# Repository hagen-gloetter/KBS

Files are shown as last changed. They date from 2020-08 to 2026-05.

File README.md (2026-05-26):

# KBS – Kinder Benachrichtigungs System

**English:** Tired of shouting through the house to call the kids for dinner or to get up? The Child Notification System (KBS) is a Raspberry Pi-based solution using a 16x2 LCD display and a piezo buzzer. Messages are sent via a REST API, so any system capable of HTTP POST requests can trigger notifications.

**Deutsch:** Ist es nicht nervig, immer durch das Haus oder die Wohnung zu brüllen, um die Kinder zum Essen oder Aufstehen zu rufen? Das Kinder Benachrichtigungs System (KBS) löst genau dieses Problem. Das System basiert auf einem Raspberry Pi (Zero), einem 16x2 LCD-Display und einem Piezo-Buzzer. Das Display und der Buzzer werden über eine REST-API angesteuert.

## Architektur

```
┌──────────────┐     HTTP POST      ┌──────────────────┐
│  Webserver   │ ─────────────────> │  Raspberry Pi    │
│  (PHP)       │                    │  Flask API :8080 │
│              │                    │  LCD + Buzzer    │
└──────────────┘                    └──────────────────┘
```

- **Webserver** (`webserver/`): PHP-basierte Weboberfläche zum Senden von Nachrichten (Vanilla JS, keine externen Abhängigkeiten)
- **Display-Server** (`display/`): Flask REST-API auf dem Raspberry Pi, steuert LCD und Buzzer
- **3D-Gehäuse** (`3d-case/`): 3D-Druck-Dateien für das Gehäuse
- **Schaltplan** (`wiring-diagram/`): Fritzing-Datei für die Verkabelung

## Hardware

- Raspberry Pi Zero (oder vergleichbar)
- 16x2 LCD-Display mit I2C-Adapter (Adresse: `0x27`)
- Piezo-Buzzer (an GPIO Pin 15)
- Verkabelung:
  - Display: GPIO2/SDA (Pin 3), GPIO3/SCL (Pin 5)
  - Buzzer: GPIO 15 + Ground

## Installation

### Raspberry Pi vorbereiten

```bash
# Repository klonen
git clone <repository-url> ~/kbs
cd ~/kbs

# Setup-Skript ausführen (installiert Abhängigkeiten, aktiviert I2C)
sudo bash setup.sh
```

### Cronjob einrichten

```bash
# Crontab bearbeiten
crontab -e

# Folgende Zeilen einfügen:
@reboot /bin/bash /home/pi/kbs/crontab.sh
*/1 * * * * /usr/bin/python3 /home/pi/kbs/display/lcd_off.py
```

Der Cronjob startet den Flask-Server beim Boot und schaltet das Display nach 5 Minuten Inaktivität ab.

### Webserver einrichten

Die Dateien aus `webserver/` auf einen Webserver mit PHP und cURL-Unterstützung kopieren:

```bash
# Beispiel: Deployment auf den Webserver
rsync -ave ssh webserver/* user@webserver:/var/www/html/
```

## Verwendung

### REST-API (direkt)

```bash
curl -i -H "Content-Type: application/json" \
  -X POST \
  -d '{"line1":"Essen ist", "line2":"fertig!", "bell":"on", "display":"on"}' \
  http://<pi-ip>:8080/lcd/api/v1.0/lcds
```

Parameter:
| Parameter | Beschreibung | Werte |
|---|---|---|
| `line1` | Erste Zeile (max. 16 Zeichen) | Text |
| `line2` | Zweite Zeile (max. 16 Zeichen) | Text |
| `bell` | Buzzer abspielen | `on` / `off` |
| `display` | Display blinken lassen | `on` / `off` |

### Post-API (für externe Systeme)

Die `post.php` bietet eine einfache HTTP-Schnittstelle für Homeautomation-Systeme oder Skripte:

```bash
curl -X POST http://<webserver>/post.php \
  -d "line1=Essen ist" \
  -d "line2=fertig!" \
  -d "bell=on" \
  -d "display=on" \
  -d "person=K0"
```

Parameter:
| Parameter | Beschreibung | Werte | Default |
|---|---|---|---|
| `line1` | Erste Zeile (max. 16 Zeichen) | Text | Datum |
| `line2` | Zweite Zeile (max. 16 Zeichen) | Text | Uhrzeit |
| `bell` | Buzzer abspielen | `on` / `off` | `off` |
| `display` | Display blinken lassen | `on` / `off` | `off` |
| `person` | Zielperson | `K0` (alle) / `K1` / `K2` / `K3` | `K0` |

Antwort: JSON mit Ergebnis pro Ziel-Pi.

### Weboberfläche

Die PHP-Weboberfläche bietet:
- Vordefinierte Nachrichtenvorlagen (`texte.json`)
- Auswahl der Zielperson (einzelne Kinder oder alle)
- Klingel- und Blink-Optionen

## Deployment

```bash
# Auf alle Raspberry Pis und den Webserver deployen
bash deploy.sh
```

## Projektstruktur

```
KBS/
├── display/                # Flask-Server und Hardware-Steuerung
│   ├── socket_server.py    # Haupt-Server (aktuelle Version)
│   ├── bootscreen.py       # Zeigt Hostname/IP beim Boot
│   ├── buzzer3.py          # Buzzer-Steuerung
│   ├── lcd_blink.py        # Display-Blink-Funktion
│   ├── lcd_off.py          # Display-Abschaltung (Cronjob)
│   ├── lcddriver.py        # LCD I2C-Treiber
│   └── i2c_lib.py          # I2C-Bibliothek
├── webserver/              # PHP-Weboberfläche
│   ├── config.php          # Zentrale Konfiguration (Hosts, Ports, Personen)
│   ├── index.php           # Haupt-UI
│   ├── post.php            # API-Proxy (mit Zielauswahl)
│   ├── edit.php            # Vorlagen-Editor (Legacy)
│   ├── texte.json          # Nachrichtenvorlagen
│   └── css/style.css       # Eigenes CSS (keine externen Abhängigkeiten)
├── 3d-case/                # 3D-Druck-Dateien
├── wiring-diagram/         # Fritzing-Schaltplan
├── setup.sh                # Installations-Skript
├── deploy.sh               # Deployment-Skript
├── crontab.sh              # Startup-Skript
└── crontab-install.txt     # Crontab-Vorlage
```

## Konfiguration

Alle netzwerkspezifischen Einstellungen werden zentral in `webserver/config.php` verwaltet:

```php
$KBS_TARGETS = array(
    'K1' => array('name' => 'Ramona', 'host' => 'pi-zero1.fritz.box', 'emoji' => '&#x1F467;'),
    'K2' => array('name' => 'Denise', 'host' => 'pi-zero2.fritz.box', 'emoji' => '&#x1F467;'),
    'K3' => array('name' => 'Vater',  'host' => 'pi-zero3.fritz.box', 'emoji' => '&#x1F468;'),
);
```

Neue Personen/Pis können einfach als weitere Einträge ergänzt werden. Die Weboberfläche generiert die Radio-Buttons automatisch aus dieser Konfiguration.

Weitere Einstellungen:
- `KBS_API_PORT` — Port der Flask-Server (Default: 8080)
- `KBS_CURL_TIMEOUT` — cURL-Timeout in Sekunden (Default: 10)
- `KBS_CURL_CONNECT_TIMEOUT` — Connect-Timeout (Default: 5)

Die Deployment-Ziele in `deploy.sh` müssen separat angepasst werden.

## Bekannte Einschränkungen

- Keine Authentifizierung auf der REST-API (nur für lokale Netzwerke geeignet)
- Maximale Textlänge: 16 Zeichen pro Zeile (Hardware-Limitation)
- `socket_server_v1.py`, `socket_server_v2.py`, `socket_server_v3.py` sind ältere Entwicklungsversionen
- `buzzer.py`, `buzzer2.py` sind ältere Test-Dateien (Python 2-Syntax, nicht aktiv genutzt)
- `template.html`, `edit.php`, `styles.css` sind Legacy-Dateien (nicht aktiv genutzt)

## Lizenz

Siehe Projektdateien.

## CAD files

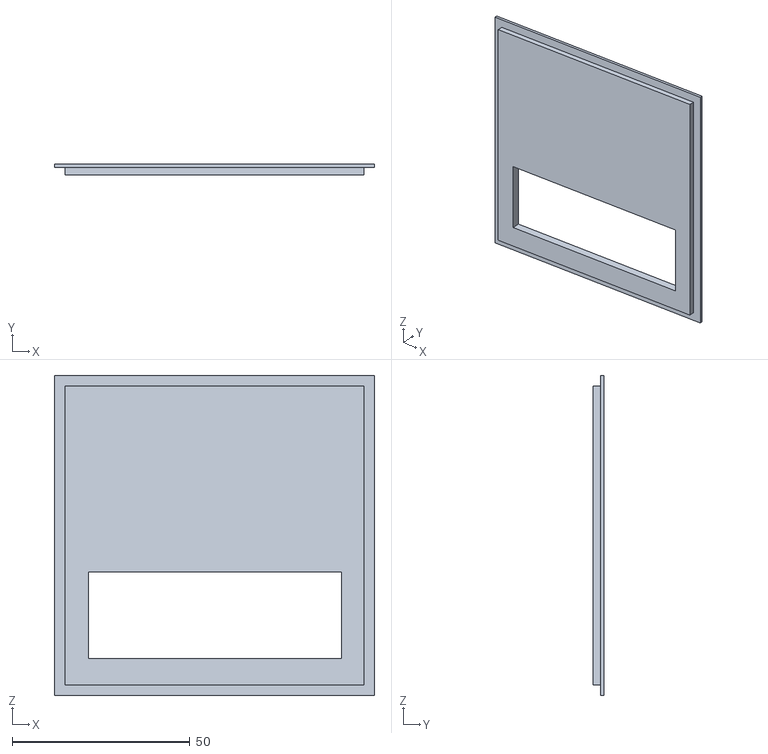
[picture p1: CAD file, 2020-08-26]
3d-case/Display Deckel v7.stl
90.0 x 3.00 x 90.0

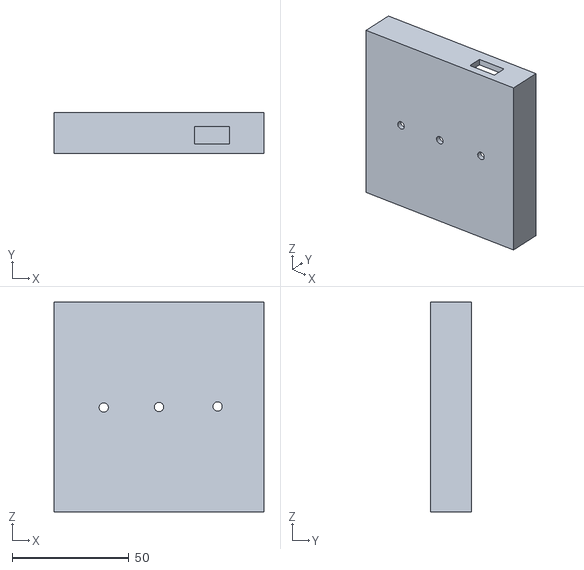
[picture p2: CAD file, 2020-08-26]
3d-case/Display Body v7.stl
90.0 x 17.5 x 90.0

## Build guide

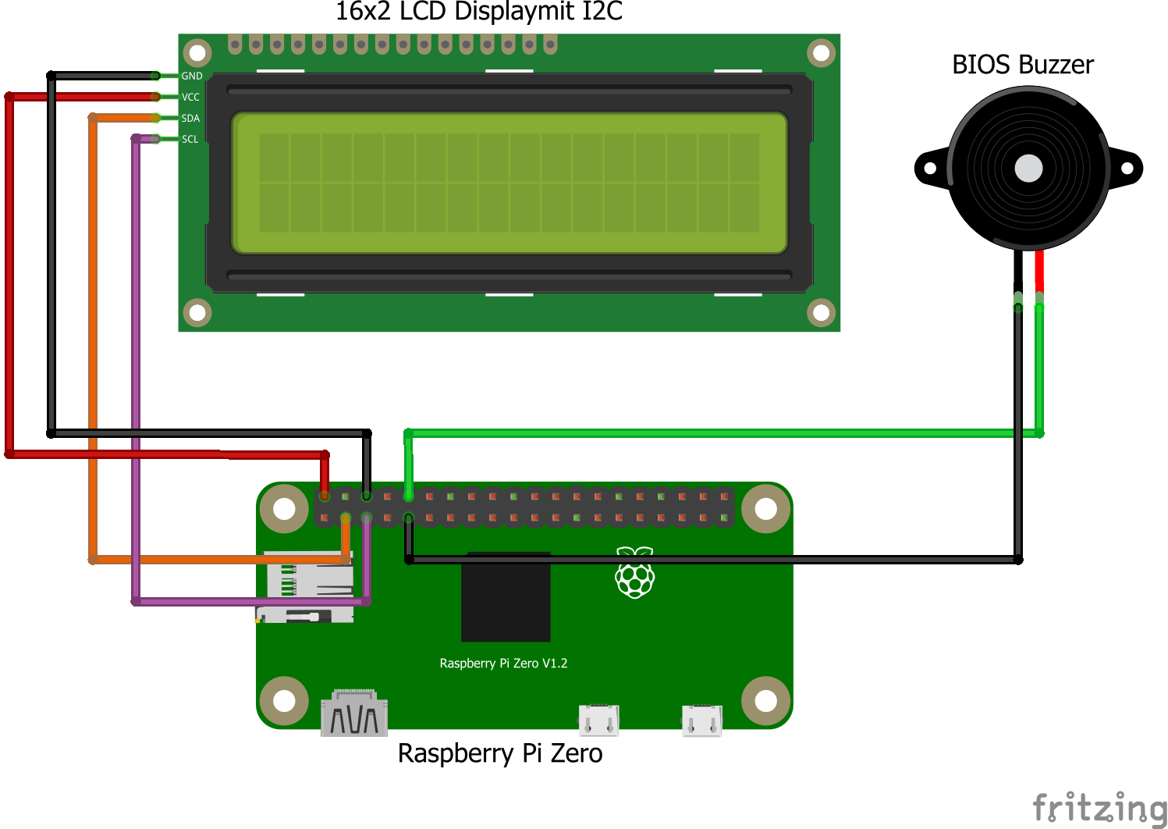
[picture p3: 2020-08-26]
wiring-diagram/KBS-KinderBenachrichtigungsSystem_Steckplatine.png

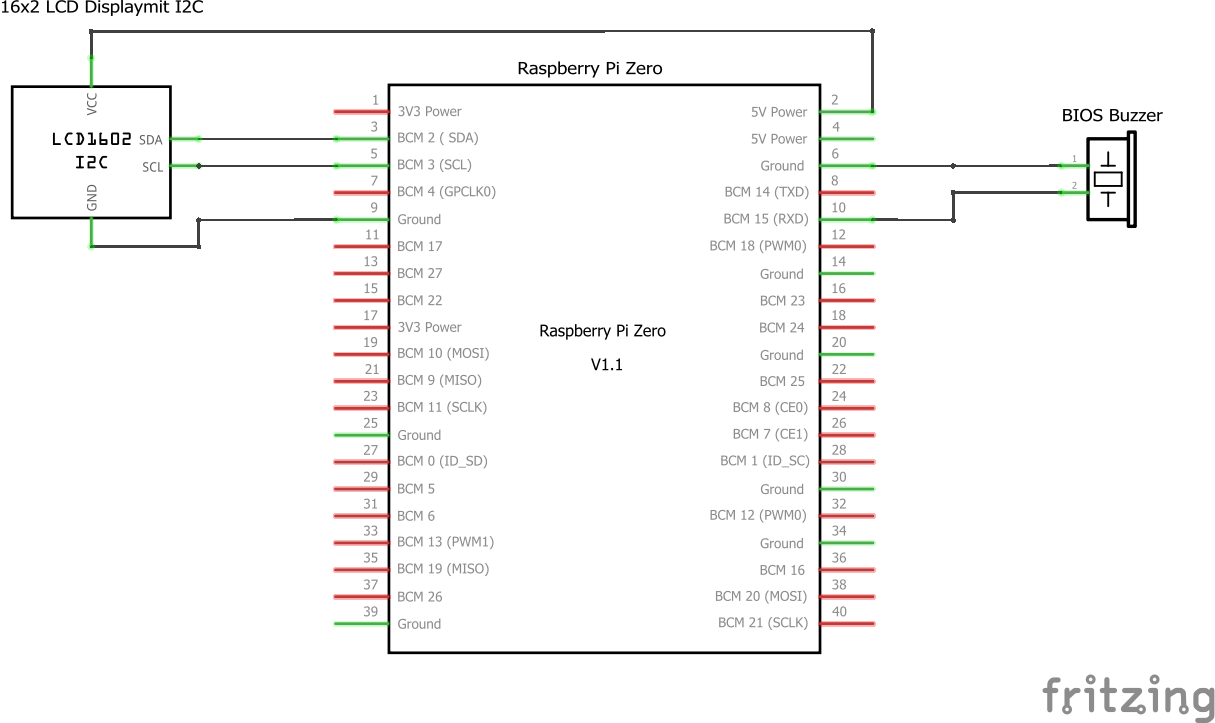
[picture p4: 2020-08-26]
wiring-diagram/KBS-KinderBenachrichtigungsSystem_Schaltplan.png

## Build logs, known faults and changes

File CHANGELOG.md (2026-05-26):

# Changelog

Alle wesentlichen Änderungen an diesem Projekt werden in dieser Datei dokumentiert.

Das Format basiert auf [Keep a Changelog](https://keepachangelog.com/de/1.0.0/),
und dieses Projekt verwendet [Semantic Versioning](https://semver.org/lang/de/).

## [Unreleased]

### Removed
- **[Medium]** jQuery 3.7.1 komplett entfernt — kein JavaScript-Framework mehr nötig
- **[Medium]** Bootstrap 4 CSS und JS komplett entfernt — kein CSS-Framework mehr nötig
- **[Medium]** Unbenutzte JS-Dateien gelöscht: `jquery-3.7.1.min.js`, `jquery.min.js`, `popper.min.js`, `bootstrap.min.js`, `scripts.js`
- **[Medium]** Unbenutzte CSS-Dateien gelöscht: alle `bootstrap*.css` und zugehörige `.map`-Dateien
- **[Low]** Leeres `webserver/fonts/`-Verzeichnis gelöscht
- **[Low]** IE-Edge-Compatibility Meta-Tag (`X-UA-Compatible`) entfernt (veraltet, nicht mehr relevant)
- **[Low]** Bootstrap-spezifische `data-dismiss`-Attribute durch Vanilla JS `onclick`-Handler ersetzt

### Added
- **[Medium]** `config.php`: Zentrale Konfigurationsdatei für Pi-Hostnamen, Ports, Timeouts und Personenzuordnungen
- **[Medium]** `post.php`: Optionaler `person`-Parameter für Zielauswahl (K0=alle, K1/K2/K3=einzeln)
- **[Medium]** `post.php`: Multi-Target-Unterstützung — sendet an mehrere Pis und gibt Ergebnis pro Ziel zurück
- **[Medium]** Vollständig eigenes CSS (`css/style.css`) mit CSS Custom Properties, modernen Toggle-Switches, Custom Radio-Buttons, Card-Layout, Responsive Design
- **[Medium]** Vanilla JavaScript für Vorlagen-Laden (`fetch()` API statt jQuery `$.getJSON()`)
- **[Medium]** CSS-only Toggle-Switches statt Bootstrap Custom Switches
- **[Medium]** CSS-only Custom Radio-Buttons mit Übergangsanimationen
- **[Low]** Docstrings und Modul-Header für alle Python-Dateien hinzugefügt
- **[Low]** PHPDoc-Blöcke für PHP-Dateien hinzugefügt
- **[Low]** Kommentare für Shell-Skripte (`setup.sh`, `deploy.sh`, `crontab.sh`) ergänzt
- **[Low]** CSS-Animation `alertSlideIn` für Statusmeldungen
- **[Low]** Responsive Media-Queries für Mobile-Geräte (< 480px)
- **[Low]** CSS-Placeholder-Styling für LCD-Eingabefelder

### Changed
- **[Medium]** `index.php`: Pi-Targets über `config.php` statt hardcoded Arrays
- **[Medium]** `index.php`: Radio-Buttons werden dynamisch aus `$KBS_TARGETS` generiert
- **[Medium]** `index.php`: cURL-Timeouts über Konstanten aus `config.php`
- **[Medium]** `index.php`: Komplettes Frontend-Rewrite ohne externe Abhängigkeiten (jQuery, Bootstrap)
- **[Medium]** `index.php`: Alert-HTML vereinfacht (`alert-close` + `onclick` statt Bootstrap JS)
- **[Medium]** `post.php`: Nutzt jetzt `config.php` für Ziel-URLs statt hardcoded `pi-zero1`
- **[Low]** `buzzer2.py`: Niederländische Kommentare und Texte ins Englische übersetzt
- **[Low]** Version-Bump von v2.0 auf v3.0
- **[Low]** `README.md`: Konfiguration, post.php-API und Legacy-Dateien dokumentiert

### Fixed (Legacy-Dateien)
- **[High]** `buzzer.py`: Tune 2 Duration-Bug — `[0.2,0.2,0.2,0.2,0.2,0,5]` → `[0.2,0.2,0.2,0.2,0.5]`
- **[High]** `buzzer.py`: GPIO-Pin-Kommentar korrigiert (sagte Pin 5, war bereits Pin 15)
- **[High]** `buzzer.py`: `__main__`-Guard mit Input-Validierung und `GPIO.cleanup()` im `finally`-Block
- **[High]** `buzzer2.py`: Python 2 Print-Syntax `print "text"` → Python 3 `print("text")`
- **[High]** `buzzer2.py`: GPIO-Pin von 5 auf 15 korrigiert (konsistent mit Hardware-Doku)
- **[High]** `socket_server_v1.py`: Fehlende Imports `abort`, `make_response` ergänzt
- **[High]** `socket_server_v1.py`: Task-Dictionary speicherte String-Literale `"line1"` statt Variablen
- **[High]** `socket_server_v1.py`: Python 2 Print-Syntax in `lcd_off_timer()` → Python 3
- **[High]** `socket_server_v1.py`: Port von 80 auf 8080 korrigiert (konsistent mit aktuellem Server)
- **[High]** `socket_server_v2.py`: Fehlende Imports `abort`, `make_response` ergänzt
- **[High]** `socket_server_v2.py`: `play()`-Methode war außerhalb der Buzzer-Klasse (falsche Einrückung)
- **[High]** `socket_server_v2.py`: Task-Dictionary speicherte String-Literale statt Variablen
- **[High]** `socket_server_v2.py`: `pass` statt `return jsonify()` in `create_task()` behoben
- **[High]** `socket_server_v2.py`: Tune 2 Duration-Bug behoben
- **[High]** `socket_server_v2.py`: GPIO-Pin von 5 auf 15 korrigiert
- **[Medium]** `socket_server_v2.py`: Nicht-funktionales `asyncio`-Import und Decorators entfernt
- **[High]** `socket_server_v3.py`: Gleiche Fixes wie v2 (Imports, play()-Einrückung, Task-Dict, return, Tune 2, Pin)
- **[Medium]** `socket_server_v3.py`: Nicht verfügbares `grequests`-Import entfernt
- **[Medium]** `template.html`: Referenzen auf gelöschte Bootstrap/jQuery-Dateien entfernt
- **[Medium]** `template.html`: Doppelte Radio-Button-ID `optionsRadios2` → `optionsRadios2a`
- **[Medium]** `template.html`: Base64-Data-URI-Inline-Styles aus Input-Feldern entfernt
- **[Low]** `template.html`: LayoutIt-Meta-Tags entfernt, IE-Compat-Meta entfernt
- **[Medium]** `edit.php`: Externes Google Fonts CDN entfernt (Datenschutz/Privacy)
- **[Low]** `edit.php`: Tutorial-Variablennamen (`superHeroes`, `heroes`) durch `jsonData`, `templates` ersetzt
- **[Low]** `edit.php`: `populateHeader()` auf KBS-Felder angepasst statt Tutorial-Felder

### Security
- **[Critical]** jQuery 3.3.1 → 3.7.1 aktualisiert (CVE-2020-11022, CVE-2020-11023, CVE-2019-11358)
- **[High]** jQuery wird jetzt lokal geladen statt vom CDN (keine externe Abhängigkeit, kein Supply-Chain-Risiko)
- **[Critical]** XSS-Schwachstelle in `index.php` durch unsanitisiertes `$_SERVER['PHP_SELF']` behoben
- **[Critical]** OS-Command-Injection in `socket_server.py` behoben — `os.system()` durch `subprocess.Popen()` ersetzt
- **[Critical]** Uninitialisiertes `$myObj` in `index.php` und `post.php` behoben
- **[High]** Fehlende `htmlspecialchars()`-Sanitisierung für `$person` in `index.php` hinzugefügt
- **[High]** Fehlende Input-Validierung in Flask-API — JSON-Felder werden jetzt sicher mit `.get()` und Defaults gelesen
- **[High]** Input-Sanitisierung für LCD-Text hinzugefügt (Längenbegrenzung, Steuerzeichen-Filter)
- **[High]** XSS in `index.php` `send_message_to_pi()` — URL/Content werden jetzt escaped in Fehlermeldungen
- **[Medium]** XSS in `index.php` value-Attributen — `$line1`/`$line2` Output jetzt mit `htmlspecialchars()`
- **[Medium]** jQuery CDN-Einbindung mit SRI-Hash (Subresource Integrity) abgesichert
- **[Medium]** cURL-Timeout (10s) und Connect-Timeout (5s) in `send_message_to_pi()` hinzugefügt

### Fixed
- **[High]** Fehlende Imports (`abort`, `make_response`) in `socket_server.py` ergänzt
- **[High]** Unbenutzte Imports (`requests`, `threading`, `Response`, `RPi.GPIO`) in `socket_server.py` entfernt
- **[High]** Switch-Statement-Bug in `index.php`: `case 200 || 201:` (immer `true`) zu separaten Cases korrigiert
- **[High]** `curl_errno()` nach `curl_close()` in `index.php` behoben — Fehler wird jetzt vor dem Schließen gespeichert
- **[High]** Tautologische Bedingung bei Radio-Buttons in `index.php` korrigiert (`||` → `&&`)
- **[High]** `post.php`: Variable `$display` wurde mit `$_POST['zielperson']` überschrieben
- **[High]** `post.php`: Ungültiges `return` auf Top-Level entfernt
- **[High]** Task-Dictionary in `socket_server.py` speicherte String-Literale statt Variablenwerte
- **[High]** `bootscreen.py`: `not in` → `!=` — Substring-Check statt Gleichheitsprüfung ergab falsche Ergebnisse
- **[High]** `lcddriver.py`: Backlight-State-Tracking — Backlight wurde bei jedem `lcd_write()` wieder eingeschaltet, da `LCD_BACKLIGHT` hardcoded war. Jetzt wird `self.backlight_state` in `lcd_strobe()` und `lcd_write_four_bits()` verwendet
- **[High]** `buzzer3.py`: Tune 2 Duration-Bug — `[0.2,0.2,0.2,0.2,0.2,0,5]` war `0` und `5` statt `0.5`, Array hatte 7 Elemente für 5 Pitches
- **[Medium]** `bootscreen.py`: Python 3-Kompatibilität für `struct.pack()` (bytes statt string)
- **[Medium]** `lcd_blink.py`: Validierungslogik `or` → `and` (war immer true)
- **[Medium]** `lcd_off.py`: Fehlender `if __name__ == '__main__'`-Guard hinzugefügt
- **[Medium]** `lcd_off.py`: Doppelter `__main__`-Block entfernt
- **[Medium]** `lcd_off.py`: Unnötiger `heute.weekday()`-Aufruf ohne Zuweisung entfernt
- **[Medium]** `lcd_off.py`: Wochentagsnamen auf 2 Zeichen gekürzt (Zeile 2 passte nicht in 16 Zeichen, z.B. "Donnerstag, 13.05." = 20 Zeichen)
- **[Medium]** `lcddriver.py`: `sys.path.append("./lib")` durch absoluten Pfad ersetzt — funktioniert jetzt auch wenn aus anderem Verzeichnis gestartet (z.B. Crontab)
- **[Medium]** `i2c_lib.py`: Wildcard-Import `from time import *` durch `from time import sleep` ersetzt
- **[Medium]** `lcddriver.py`: Wildcard-Import `from time import *` durch `from time import sleep` ersetzt
- **[Medium]** `i2c_lib.py`: Unnötiges `sys.path.append("./lib")` entfernt
- **[Medium]** `socket_server.py`: File-Handle-Leak bei lastrun-Erstellung behoben (`with`-Statement)
- **[Medium]** `index.php`: Variable `$person` im else-Branch initialisiert (vermeidet undefined-Warnung)
- **[Medium]** `index.php`: Zero-Width-Character (U+200B) im HTML entfernt
- **[Medium]** `crontab-install.txt`: Falscher Pfad `16x2_Display` → `kbs` korrigiert
- **[Medium]** `crontab.sh`: `python` → `python3` für bootscreen.py; stderr-Redirect hinzugefügt
- **[Low]** `socket_server.py`: Tasks-Liste auf 100 Einträge begrenzt (Memory-Leak verhindert)

### Changed
- **[Medium]** `setup.sh`: Python 2-Abhängigkeiten entfernt, nur noch Python 3
- **[Medium]** `setup.sh`: `/etc/modules`-Einträge werden nur hinzugefügt wenn nicht vorhanden
- **[Medium]** `setup.sh`: `-y` Flag für `apt-get install` hinzugefügt
- **[Medium]** `setup.sh`: Nutzt jetzt `requirements.txt` statt manueller `pip3 install`-Befehle
- **[Low]** `deploy.sh`: Excludes für `.git`, `__pycache__`, Logs, `3d-case`, `wiring-diagram`, `webserver/`, Docs
- **[Low]** `lcd_off.py`: Unbenutzten `RPi.GPIO`-Import und doppelte `strftime`-Aufrufe entfernt
- **[Low]** `lcddriver.py`: `lcd_backlight()` nutzt `state.lower()` statt expliziter Aufzählung
- **[Medium]** `post.php`: Komplett modernisiert — Port 8080, Timeout, JSON-Response, sauberes Error-Handling

### Added
- `requirements.txt` für Python-Abhängigkeiten erstellt
- `.gitignore` erstellt
- `CHANGELOG.md` erstellt
- `SECURITY.md` erstellt
- `README.md` umfassend aktualisiert mit Setup-Anleitung, API-Dokumentation und Projektstruktur
- `socket_server.py`: Error-Handler für 400 Bad Request hinzugefügt
- `socket_server.py`: Health-Endpoint (`GET /health`) und GET-Endpoint für alle Tasks
- `socket_server.py`: Task-IDs und Timestamps für jeden gesendeten Task
- `socket_server.py`: Strukturiertes Logging mit Zeitstempel statt print()
- `socket_server.py`: JSON-Info auf Root-Endpoint (`/`) mit API-Übersicht
- `index.php`: Komplettes Webseiten-Redesign mit modernem Card-Layout
- `index.php`: LCD-Vorschau-Styling (monospace, grüne Schrift auf dunkelgrün)
- `index.php`: Vorlagen werden bei Select-Änderung automatisch übernommen
- `index.php`: Pi-Targets als konfigurierbare Array-Struktur statt if/elseif-Kette
- `index.php`: Status-Alerts pro Pi (einzelne Erfolg/Fehler-Meldungen)
- `css/style.css`: Eigenes CSS mit Cards, Shadows, abgerundeten Ecken
- `js/jquery-3.7.1.min.js`: jQuery lokal eingebunden

### Improved
- `bootscreen.py`: Socket wird jetzt geschlossen, LCD in main() initialisiert, saubere Fehlerbehandlung
- `bootscreen.py`: get_ip() gibt Exception-basiert "Not connected" zurück statt finally-return
- `bootscreen.py`: Hostname wird nur einmal ermittelt statt in jeder Schleife
- `lcd_blink.py`: Unbenutzter RPi.GPIO-Import entfernt, Eingabe-Validierung mit ValueError-Handling
- `buzzer3.py`: GPIO.cleanup() im finally-Block, Input-Validierung mit Bereichsprüfung
- `texte.json`: Vorlagen auf max. 16 Zeichen korrigiert, konsistente Formatierung
- `texte.json`: "Aufstehen" und "SOFORT"-Vorlagen mit Blinken aktiviert

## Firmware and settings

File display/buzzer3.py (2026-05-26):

#! /usr/bin/python3
# -*- coding: utf-8 -*-
#
# KBS – Buzzer-Steuerung (aktive Version)
# Spielt verschiedene Melodien ueber einen Piezo-Buzzer an GPIO Pin 15.
#
# Verwendung: python3 buzzer3.py <Tune 1-5>
#
# Tunes:
#   1 – Tonleiter auf/ab (C4-C6)
#   2 – Aufsteigend kurz
#   3 – Melodie mit Pausen
#   4 – Absteigend hoch
#   5 – Absteigend tief
#
# Hardware: Piezo-Buzzer an GPIO 15 + Ground
#

import RPi.GPIO as GPIO   #import the GPIO library
import time               #import the time library
import sys


class Buzzer(object):
 def __init__(self):
  GPIO.setmode(GPIO.BCM)  
  self.buzzer_pin = 15 #set to GPIO pin 15
  GPIO.setup(self.buzzer_pin, GPIO.IN)
  GPIO.setup(self.buzzer_pin, GPIO.OUT)
  print("buzzer ready")

 def __del__(self):
  class_name = self.__class__.__name__
  print (class_name, "finished")
  
 def buzz(self,pitch,duration):
  if(pitch==0):
   time.sleep(duration)
   return
  period = 1.0 / pitch     #in physics, the period (sec/cyc) is the inverse of the frequency (cyc/sec)
  delay = period / 2     #calcuate the time for half of the wave  
  cycles = int(duration * pitch)   #the number of waves to produce is the duration times the frequency

  for i in range(cycles):
   GPIO.output(self.buzzer_pin, True)   #set pin 18 to high
   time.sleep(delay)
       #wait with pin 18 high
   GPIO.output(self.buzzer_pin, False)
       #set pin 18 to low
   time.sleep(delay)
       #wait with pin 18 low

 def play(self, tune):
  GPIO.setmode(GPIO.BCM)
  GPIO.setup(self.buzzer_pin, GPIO.OUT)
  x=0

  print("Playing tune ",tune)
  if(tune==1):
    pitches=[262,294,330,349,392,440,494,523, 587, 659,698,784,880,988,1047]
    duration=0.1
    for p in pitches:
      self.buzz(p, duration)
      time.sleep(duration *0.5)
    for p in reversed(pitches):
      self.buzz(p, duration)
      time.sleep(duration *0.5)

  elif(tune==2):
    pitches=[262,330,392,523,1047]
    duration=[0.2,0.2,0.2,0.2,0.5]
    for p in pitches:
      self.buzz(p, duration[x])
      time.sleep(duration[x] *0.5)
      x+=1
  elif(tune==3):
    pitches=[392,294,0,392,294,0,392,0,392,392,392,0,1047,262]
    duration=[0.2,0.2,0.2,0.2,0.2,0.2,0.1,0.1,0.1,0.1,0.1,0.1,0.8,0.4]
    for p in pitches:
      self.buzz(p, duration[x])
      time.sleep(duration[x] *0.5)
      x+=1

  elif(tune==4):
    pitches=[1047, 988,659]
    duration=[0.1,0.1,0.2]
    for p in pitches:
      self.buzz(p, duration[x])
      time.sleep(duration[x] *0.5)
      x+=1

  elif(tune==5):
    pitches=[1047, 988,523]
    duration=[0.1,0.1,0.2]
    for p in pitches:
      self.buzz(p, duration[x])
      time.sleep(duration[x] *0.5)
      x+=1

  GPIO.setup(self.buzzer_pin, GPIO.IN)


def main():
    if len(sys.argv) < 2:
        print("Verwendung: python3 buzzer3.py <Tune 1-5>")
        sys.exit(1)
    try:
        zahl = int(sys.argv[1])
    except ValueError:
        print("Fehler: Bitte eine Zahl zwischen 1 und 5 angeben.")
        sys.exit(1)
    if zahl < 1 or zahl > 5:
        print("Fehler: Tune muss zwischen 1 und 5 liegen.")
        sys.exit(1)
    buzzer = Buzzer()
    try:
        buzzer.play(zahl)
    finally:
        GPIO.cleanup()


if __name__ == "__main__":
    main()

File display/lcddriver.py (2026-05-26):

#
# KBS – LCD I2C Treiber
# Steuert ein HD44780-kompatibles LCD-Display ueber einen PCF8574 I2C-Adapter.
#
# Unterstuetzt 16x2 und 20x4 Displays mit I2C-Adresse 0x27.
# Basiert auf dem raspberry_lcd4x20_I2C Projekt.
#

import sys
import os
sys.path.append(os.path.join(os.path.dirname(os.path.abspath(__file__)), "lib"))

import i2c_lib
from time import sleep

# LCD Address
ADDRESS = 0x27

# commands
LCD_CLEARDISPLAY = 0x01
LCD_RETURNHOME = 0x02
LCD_ENTRYMODESET = 0x04
LCD_DISPLAYCONTROL = 0x08
LCD_CURSORSHIFT = 0x10
LCD_FUNCTIONSET = 0x20
LCD_SETCGRAMADDR = 0x40
LCD_SETDDRAMADDR = 0x80

# flags for display entry mode
LCD_ENTRYRIGHT = 0x00
LCD_ENTRYLEFT = 0x02
LCD_ENTRYSHIFTINCREMENT = 0x01
LCD_ENTRYSHIFTDECREMENT = 0x00

# flags for display on/off control
LCD_DISPLAYON = 0x04
LCD_DISPLAYOFF = 0x00
LCD_CURSORON = 0x02
LCD_CURSOROFF = 0x00
LCD_BLINKON = 0x01
LCD_BLINKOFF = 0x00

# flags for display/cursor shift
LCD_DISPLAYMOVE = 0x08
LCD_CURSORMOVE = 0x00
LCD_MOVERIGHT = 0x04
LCD_MOVELEFT = 0x00

# flags for function set
LCD_8BITMODE = 0x10
LCD_4BITMODE = 0x00
LCD_2LINE = 0x08
LCD_1LINE = 0x00
LCD_5x10DOTS = 0x04
LCD_5x8DOTS = 0x00

# flags for backlight control
LCD_BACKLIGHT = 0x08
LCD_NOBACKLIGHT = 0x00

En = 0b00000100 # Enable bit
Rw = 0b00000010 # Read/Write bit
Rs = 0b00000001 # Register select bit

class lcd:
   #initializes objects and lcd
   def __init__(self):
      self.lcd_device = i2c_lib.i2c_device(ADDRESS)
      self.backlight_state = LCD_BACKLIGHT

      self.lcd_write(0x03)
      self.lcd_write(0x03)
      self.lcd_write(0x03)
      self.lcd_write(0x02)

      self.lcd_write(LCD_FUNCTIONSET | LCD_2LINE | LCD_5x8DOTS | LCD_4BITMODE)
      self.lcd_write(LCD_DISPLAYCONTROL | LCD_DISPLAYON)
      self.lcd_write(LCD_CLEARDISPLAY)
      self.lcd_write(LCD_ENTRYMODESET | LCD_ENTRYLEFT)
      sleep(0.2)

   # clocks EN to latch command
   def lcd_strobe(self, data):
      self.lcd_device.write_cmd(data | En | self.backlight_state)
      sleep(.0005)
      self.lcd_device.write_cmd(((data & ~En) | self.backlight_state))
      sleep(.0001)

   def lcd_write_four_bits(self, data):
      self.lcd_device.write_cmd(data | self.backlight_state)
      self.lcd_strobe(data)

   # write a command to lcd
   def lcd_write(self, cmd, mode=0):
      self.lcd_write_four_bits(mode | (cmd & 0xF0))
      self.lcd_write_four_bits(mode | ((cmd << 4) & 0xF0))
      
   #turn on/off the lcd backlight
   def lcd_backlight(self, state):
      if state.lower() == "on":
         self.backlight_state = LCD_BACKLIGHT
      elif state.lower() == "off":
         self.backlight_state = LCD_NOBACKLIGHT
      else:
         print ("Unknown State!")
      self.lcd_device.write_cmd(self.backlight_state)

   # put string function
   def lcd_display_string(self, string, line):
      if line == 1:
         self.lcd_write(0x80)
      if line == 2:
         self.lcd_write(0xC0)
      if line == 3:
         self.lcd_write(0x94)
      if line == 4:
         self.lcd_write(0xD4)

      for char in string:
         self.lcd_write(ord(char), Rs)

   # clear lcd and set to home
   def lcd_clear(self):
      self.lcd_write(LCD_CLEARDISPLAY)
      self.lcd_write(LCD_RETURNHOME)

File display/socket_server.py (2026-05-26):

#! /usr/bin/python3
# -*- coding: UTF-8 -*-
#
# KBS – Kinder Benachrichtigungs System
# Flask REST-API fuer LCD-Display und Buzzer auf dem Raspberry Pi
#
# Hardware:
#   Display: GPIO2/SDA (Pin 3), GPIO3/SCL (Pin 5)
#   Buzzer:  GPIO 15, Ground
#
# Start: python3 socket_server.py

from flask import Flask, jsonify, abort, make_response, request
import subprocess
import os
import sys
import time
import logging

# Logging konfigurieren
logging.basicConfig(
    level=logging.INFO,
    format='%(asctime)s [%(levelname)s] %(message)s',
    datefmt='%Y-%m-%d %H:%M:%S'
)
logger = logging.getLogger(__name__)

app = Flask(__name__)

# Task-Speicher
tasks = []
MAX_TASKS = 100
next_task_id = 1

import lcddriver

lcd = lcddriver.lcd()
mypath = os.path.dirname(os.path.abspath(__file__))
logger.info("Arbeitsverzeichnis: %s", mypath)

# Maximale Laenge fuer LCD-Zeilen (16x2 Display)
MAX_LINE_LENGTH = 16

def sanitize_lcd_text(text):
    """Begrenze Text auf erlaubte Laenge und entferne Steuerzeichen.

    Nur druckbare ASCII-Zeichen (32-126) werden durchgelassen,
    da das LCD keine Unicode-Zeichen darstellen kann.

    Args:
        text: Eingabetext (wird bei Bedarf zu String konvertiert)

    Returns:
        Bereinigter Text, maximal MAX_LINE_LENGTH Zeichen
    """
    if not isinstance(text, str):
        text = str(text)
    # Nur druckbare ASCII-Zeichen erlauben (LCD-kompatibel)
    text = ''.join(c for c in text if 32 <= ord(c) < 127)
    return text[:MAX_LINE_LENGTH]

@app.route('/')
def index():
    return jsonify({
        'name': 'KBS - Kids Room Information System',
        'version': '2.0',
        'endpoints': {
            'POST /lcd/api/v1.0/lcds': 'Nachricht an LCD senden',
            'GET /lcd/api/v1.0/lcds': 'Alle gesendeten Nachrichten abrufen',
            'GET /lcd/api/v1.0/lcds/<id>': 'Einzelne Nachricht abrufen',
            'GET /health': 'Health-Check',
        }
    })

@app.route('/health')
def health():
    return jsonify({'status': 'ok'})

@app.route('/lcd/api/v1.0/lcds', methods=['GET'])
def get_tasks():
    return jsonify({'tasks': tasks, 'count': len(tasks)})

@app.route('/lcd/api/v1.0/lcds/<int:task_id>', methods=['GET'])
def get_task(task_id):
    task = [t for t in tasks if t['id'] == task_id]
    if len(task) == 0:
        abort(404)
    return jsonify({'task': task[0]})

@app.route('/lcd/api/v1.0/lcds', methods=['POST'])
def create_task():
    global next_task_id
    if not request.json or 'line1' not in request.json:
        abort(400)
    line1 = sanitize_lcd_text(request.json.get('line1', ''))
    line2 = sanitize_lcd_text(request.json.get('line2', ''))
    bell = request.json.get('bell', 'off')
    display = request.json.get('display', 'off')
    # Nur "on"/"off" erlauben
    bell = 'on' if bell == 'on' else 'off'
    display = 'on' if display == 'on' else 'off'
    task = {
        'id': next_task_id,
        'line1': line1,
        'line2': line2,
        'bell': bell,
        'display': display,
        'timestamp': time.strftime('%Y-%m-%d %H:%M:%S'),
    }
    try:
        lcd_print(line1, line2, display, bell)
        logger.info("Nachricht gesendet: '%s' / '%s' (bell=%s, blink=%s)", line1, line2, bell, display)
    except Exception as e:
        logger.error("Fehler bei lcd_print: %s", e)
        return jsonify({'error': 'Hardware-Fehler'}), 500
    next_task_id += 1
    tasks.append(task)
    if len(tasks) > MAX_TASKS:
        tasks.pop(0)
    return jsonify({'task': task}), 201

@app.errorhandler(400)
def bad_request(error):
    return make_response(jsonify({'error': 'Bad request'}), 400)

@app.errorhandler(404)
def not_found(error):
    return make_response(jsonify({'error': 'Not found'}), 404)

def lcd_print(line1, line2, display, bell):
    """Zeigt Text auf dem LCD an und loest optional Blinken/Klingel aus.

    Args:
        line1:   Text fuer Zeile 1 (max. 16 Zeichen)
        line2:   Text fuer Zeile 2 (max. 16 Zeichen)
        display: 'on' fuer Blink-Effekt, 'off' fuer normal
        bell:    'on' fuer Buzzer, 'off' fuer stumm
    """
    lcd.lcd_clear()
    lcd.lcd_backlight("on")
    if display == "on":  # Blinken an
        lcd_blink()
    if bell == "on":     # Klingel an
        bell_play()
    time.sleep(.5)  # Pause ist wichtig, da sonst kein Text auf dem Display angezeigt wird!
    lcd.lcd_display_string(line1, 1)  # nach dem Blinken muss das Display neu gesetzt werden
    lcd.lcd_display_string(line2, 2)
    lastrun_path = os.path.join(mypath, "lastrun")
    try:
        with open(lastrun_path, 'a'):
            os.utime(lastrun_path, None)
    except OSError as e:
        logger.error("Fehler beim Erstellen von lastrun: %s", e)

def bell_play():
    """Startet buzzer3.py als Subprocess fuer den Klingelton."""
    logger.info("Bell on")
    buzzer_script = os.path.join(mypath, "buzzer3.py")
    try:
        subprocess.Popen(
            [sys.executable, buzzer_script, "1"],
            stdout=subprocess.DEVNULL,
            stderr=subprocess.DEVNULL
        )
    except OSError as e:
        logger.error("Fehler beim Starten von buzzer3.py: %s", e)

def lcd_blink():
    """Startet lcd_blink.py als Subprocess fuer den Blink-Effekt."""
    logger.info("Blink on")
    blink_script = os.path.join(mypath, "lcd_blink.py")
    try:
        subprocess.Popen(
            [sys.executable, blink_script, "30"],
            stdout=subprocess.DEVNULL,
            stderr=subprocess.DEVNULL
        )
    except OSError as e:
        logger.error("Fehler beim Starten von lcd_blink.py: %s", e)

def lcd_off_timer():
    """Schaltet das LCD-Backlight aus (wird nicht aktiv genutzt)."""
    logger.info("lcd_off_timer --> off")
    lcd.lcd_backlight("off")

if __name__ == '__main__':
    app.run(host='0.0.0.0', port=8080, threaded=True)

# Beispiel:
# curl -i -H "Content-Type: application/json" -X POST -d '{"line1":"It ", "line2":"works", "bell":"on","display":"on" }' http://192.168.4.10:8080/lcd/api/v1.0/lcds

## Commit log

2020-08-26 V1.0
    first working version
    [Display Body v7.stl, Display Deckel v7.stl, KBS-KinderBenachrichtigungsSystem.fzz]
2026-05-13 fix: Security-Fixes, Bugfixes und Dokumentation
    Critical:
    - XSS via $_SERVER['PHP_SELF'] in index.php behoben
    - OS-Command-Injection in socket_server.py (os.system → subprocess)
    - Uninitialisiertes $myObj in index.php und post.php
    High:
    - Fehlende Flask-Imports (abort, make_response) ergänzt
    - Input-Validierung und Sanitisierung in Flask-API
    - Switch-Bug (case 200||201), curl_errno nach curl_close,
    $person ohne htmlspecialchars, Radio-Button-Logik in index.php
    - post.php: $display-Überschreibung und ungültiges return
    Medium:
    - bootscreen.py: Python 3 struct.pack Kompatibilität
    - lcd_blink.py: Validierung or→and
    - lcd_off.py: __main__-Guard, unbenutzte Imports entfernt
    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
    [bootscreen.py, lcd_blink.py, lcd_off.py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]
2026-05-13 fix: Backlight-Bug, Buzzer-Bug, Pfad-Fixes, post.php modernisiert
    - lcddriver.py: Backlight-State wird jetzt getrackt – lcd_strobe/
    lcd_write_four_bits nutzten hardcoded LCD_BACKLIGHT
    - buzzer3.py: Tune 2 duration [0.2,0.2,0.2,0.2,0.2,0,5] war 0 und 5
    statt 0.5
    - lcddriver.py/i2c_lib.py: sys.path ./lib → absoluter Pfad, Wildcard-
    Imports entfernt
    - socket_server.py: File-Handle-Leak bei lastrun (with-Statement)
    - lcd_off.py: Wochentag gekürzt (passte nicht in 16 Zeichen)
    - post.php: Port 8080, Timeout, JSON-Response
    - setup.sh: nutzt requirements.txt
    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
    [bootscreen.py, buzzer3.py, i2c_lib.py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]
2026-05-26 feat: Konfiguration externalisieren, post.php Zielauswahl, Code-Dokumentation
    Konfiguration:
    - config.php: Zentrale Konfiguration für Pi-Hosts, Ports, Timeouts, Personen
    - index.php: Radio-Buttons dynamisch aus $KBS_TARGETS generiert
    - post.php: Komplett überarbeitet, nutzt config.php statt hardcoded URLs
    post.php Zielauswahl:
    - Neuer optionaler Parameter 'person' (K0=alle, K1/K2/K3=einzeln)
    - Multi-Target-Unterstützung mit JSON-Ergebnis pro Ziel
    Dokumentation:
    - Docstrings/Header für alle Python-Dateien (socket_server.py, bootscreen.py,
    lcd_off.py, lcd_blink.py, buzzer.py, buzzer2.py, buzzer3.py, lcddriver.py,
    i2c_lib.py, 16x2_Display_test.py)
    - PHPDoc-Blöcke für config.php, ind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
    [16x2_Display_test.py, bootscreen.py, buzzer.py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]
